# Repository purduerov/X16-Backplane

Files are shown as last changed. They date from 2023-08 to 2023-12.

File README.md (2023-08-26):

# Readme for X16-Backplane
This board routes signals and power between all the boards

Whenever you make a new part, download the datasheet and save it here _**and**_ with the part in the parts library

Always pull other people's changes before beginning to work
`git pull`

Be sure to push your changes after  working on them. Run:
1. `git add .` to add any files in this directory or a subdirectory
or `git add -u` to add any modified files
2. (Optional) `git clean -nX` to see what ignored files can be removed
	`git clean -fX` removes ignored files (Eagle backups)
3. `git commit -m "helpful commit message"` with a description of the work that you did
4. `git push` to push your work to github

Other helpful commands
* `git status` says information about modified and staged files
* `git log` shows the recent commits of the repository
* `git log filename.extension` show the recent commits for just that file
* `git checkout first-couple-letter-of-commit-id` lets you go back to a previous version
* `git checkout master` brings you back to the latest commit
* `git tag` lists the tags
* `git tag -a orderX -m "the version of the board placed for the X'th order"` tag a specific commit
* `git push --tags` needed to push tags to remote
* `git show orderX` show the commit log for the given tag
* `git checkout orderX` go back and interact with the files at the tagged commit

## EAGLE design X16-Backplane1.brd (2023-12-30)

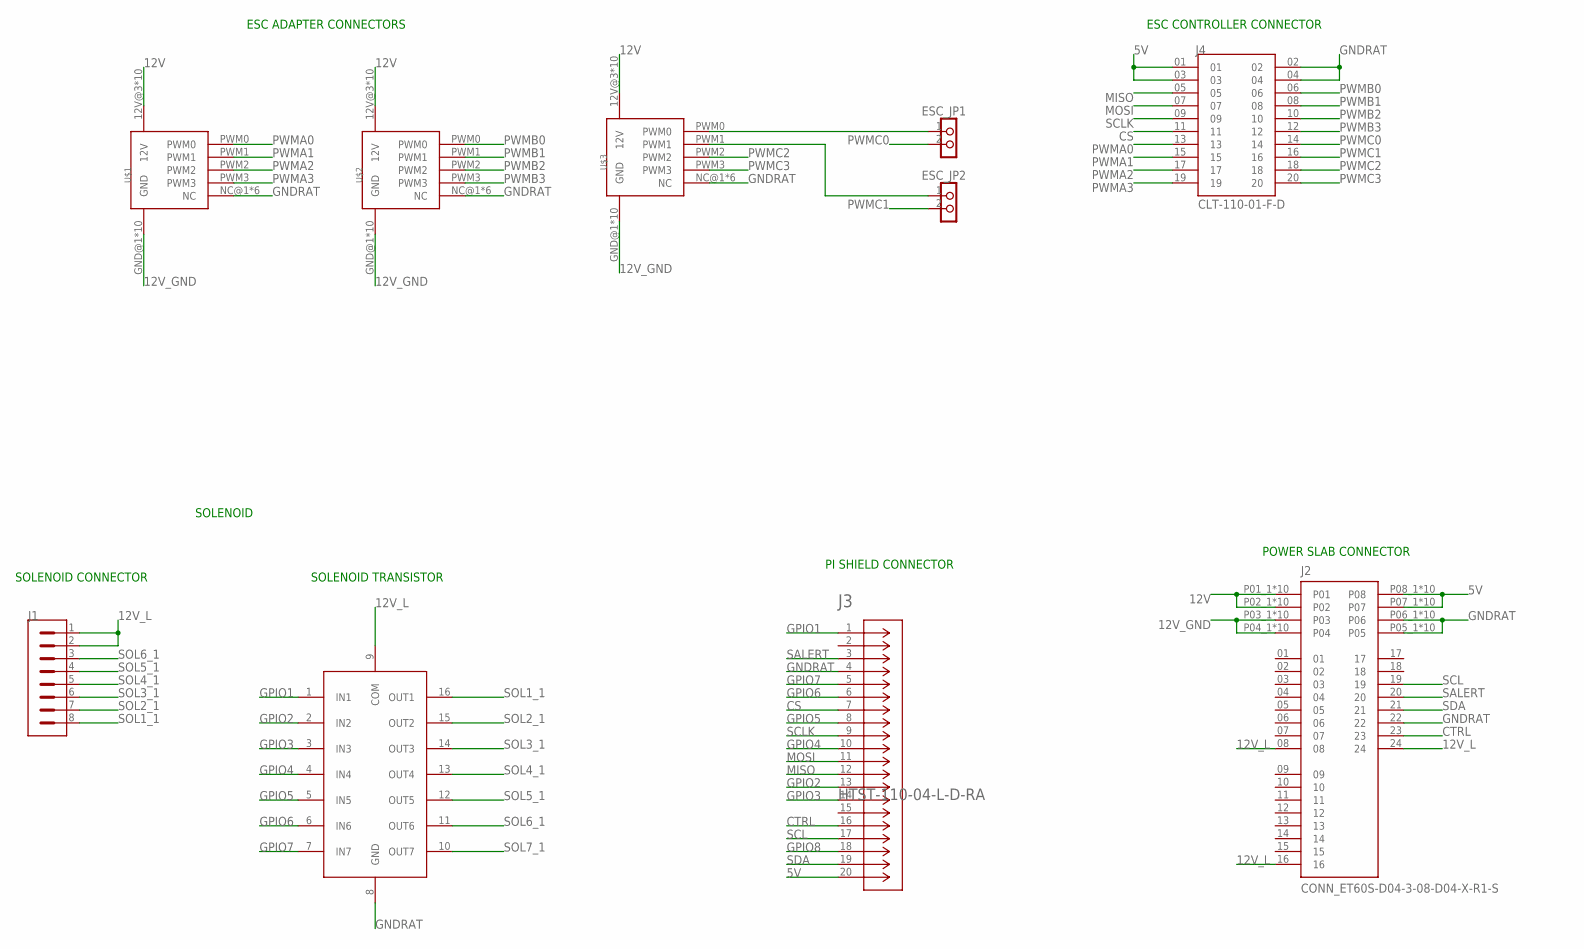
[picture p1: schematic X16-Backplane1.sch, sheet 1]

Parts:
ESC_JP1, ESC_JP2: TEST_PIN-1X2; 1X02
J1: CONN_PXC-8-RA-1778683; PXC-8-RA-1778683
J2: CONN_ET60S-D04-3-08-D04-X-R1-S; SAMTEC_ET60S-D04-3-08-D04-X-R1-S
J3: HTST-110-04-L-D-RA; CONN_HTST-110-04/05-X-D-RA_SAI
J4: CLT-110-01-F-D; SAMTEC_CLT-110-01-F-D
U2: TRANS_ULN2003AD; 16-SOIC
U$1, U$2, U$3: CONN_BACKPLANE_ESC_ADAPTER_NEW; CONN_BACKPLANE_ESC_ADAPTER

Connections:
5V: J2.P07_1 (P07), J2.P07_2 (P07), J2.P07_3 (P07), J2.P07_4 (P07), J2.P07_5 (P07), J2.P07_6 (P07), J2.P07_7 (P07), J2.P07_8 (P07), J2.P07_9 (P07), J2.P07_10 (P07), J2.P08_1 (P08), J2.P08_2 (P08), J2.P08_3 (P08), J2.P08_4 (P08), J2.P08_5 (P08), J2.P08_6 (P08), J2.P08_7 (P08), J2.P08_8 (P08), J2.P08_9 (P08), J2.P08_10 (P08), J3.20, J4.01, J4.03; also elsewhere on the board
12V: J2.P01_1 (P01), J2.P01_2 (P01), J2.P01_3 (P01), J2.P01_4 (P01), J2.P01_5 (P01), J2.P01_6 (P01), J2.P01_7 (P01), J2.P01_8 (P01), J2.P01_9 (P01), J2.P01_10 (P01), J2.P02_1 (P02), J2.P02_2 (P02), J2.P02_3 (P02), J2.P02_4 (P02), J2.P02_5 (P02), J2.P02_6 (P02), J2.P02_7 (P02), J2.P02_8 (P02), J2.P02_9 (P02), J2.P02_10 (P02), U$1.12V@3 (12V), U$1.12V@4 (12V), U$1.12V@5 (12V), U$1.12V@6 (12V), U$1.12V@7 (12V), U$1.12V@8 (12V), U$1.12V@9 (12V), U$1.12V@10 (12V), U$1.12V@11 (12V), U$1.12V@12 (12V), U$2.12V@3 (12V), U$2.12V@4 (12V), U$2.12V@5 (12V), U$2.12V@6 (12V), U$2.12V@7 (12V), U$2.12V@8 (12V), U$2.12V@9 (12V), U$2.12V@10 (12V), U$2.12V@11 (12V), U$2.12V@12 (12V), U$3.12V@3 (12V), U$3.12V@4 (12V), U$3.12V@5 (12V), U$3.12V@6 (12V), U$3.12V@7 (12V), U$3.12V@8 (12V), U$3.12V@9 (12V), U$3.12V@10 (12V), U$3.12V@11 (12V), U$3.12V@12 (12V); also elsewhere on the board
12V_GND: J2.P03_1 (P03), J2.P03_2 (P03), J2.P03_3 (P03), J2.P03_4 (P03), J2.P03_5 (P03), J2.P03_6 (P03), J2.P03_7 (P03), J2.P03_8 (P03), J2.P03_9 (P03), J2.P03_10 (P03), J2.P04_1 (P04), J2.P04_2 (P04), J2.P04_3 (P04), J2.P04_4 (P04), J2.P04_5 (P04), J2.P04_6 (P04), J2.P04_7 (P04), J2.P04_8 (P04), J2.P04_9 (P04), J2.P04_10 (P04), U$1.GND@1 (GND), U$1.GND@2 (GND), U$1.GND@3 (GND), U$1.GND@4 (GND), U$1.GND@5 (GND), U$1.GND@6 (GND), U$1.GND@7 (GND), U$1.GND@8 (GND), U$1.GND@9 (GND), U$1.GND@10 (GND), U$2.GND@1 (GND), U$2.GND@2 (GND), U$2.GND@3 (GND), U$2.GND@4 (GND), U$2.GND@5 (GND), U$2.GND@6 (GND), U$2.GND@7 (GND), U$2.GND@8 (GND), U$2.GND@9 (GND), U$2.GND@10 (GND), U$3.GND@1 (GND), U$3.GND@2 (GND), U$3.GND@3 (GND), U$3.GND@4 (GND), U$3.GND@5 (GND), U$3.GND@6 (GND), U$3.GND@7 (GND), U$3.GND@8 (GND), U$3.GND@9 (GND), U$3.GND@10 (GND); also elsewhere on the board
12V_L: J1.1, J1.2, J2.08, J2.16, J2.24, U2.9 (COM)
CS: J3.7, J4.11; also elsewhere on the board
CTRL: J2.23, J3.16
GNDRAT: J2.22, J2.P05_1 (P05), J2.P05_2 (P05), J2.P05_3 (P05), J2.P05_4 (P05), J2.P05_5 (P05), J2.P05_6 (P05), J2.P05_7 (P05), J2.P05_8 (P05), J2.P05_9 (P05), J2.P05_10 (P05), J2.P06_1 (P06), J2.P06_2 (P06), J2.P06_3 (P06), J2.P06_4 (P06), J2.P06_5 (P06), J2.P06_6 (P06), J2.P06_7 (P06), J2.P06_8 (P06), J2.P06_9 (P06), J2.P06_10 (P06), J3.4, J4.02, J4.04, U2.8 (GND), U$1.NC@1 (NC), U$1.NC@2 (NC), U$1.NC@3 (NC), U$1.NC@4 (NC), U$1.NC@5 (NC), U$1.NC@6 (NC), U$2.NC@1 (NC), U$2.NC@2 (NC), U$2.NC@3 (NC), U$2.NC@4 (NC), U$2.NC@5 (NC), U$2.NC@6 (NC), U$3.NC@1 (NC), U$3.NC@2 (NC), U$3.NC@3 (NC), U$3.NC@4 (NC), U$3.NC@5 (NC), U$3.NC@6 (NC); also elsewhere on the board
GPIO1: J3.1, U2.1 (IN1)
GPIO2: J3.13, U2.2 (IN2)
GPIO3: J3.14, U2.3 (IN3)
GPIO4: J3.10, U2.4 (IN4)
GPIO5: J3.8, U2.5 (IN5)
GPIO6: J3.6, U2.6 (IN6)
GPIO7: J3.5, U2.7 (IN7)
GPIO8: J3.18
MISO: J3.12, J4.05; also elsewhere on the board
MOSI: J3.11, J4.07; also elsewhere on the board
unnamed: ESC_JP1.1, U$3.PWM0
unnamed: ESC_JP2.1, U$3.PWM1
PWMA0: J4.13, U$1.PWM0
PWMA1: J4.15, U$1.PWM1
PWMA2: J4.17, U$1.PWM2
PWMA3: J4.19, U$1.PWM3
PWMB0: J4.06, U$2.PWM0
PWMB1: J4.08, U$2.PWM1
PWMB2: J4.10, U$2.PWM2
PWMB3: J4.12, U$2.PWM3
PWMC0: ESC_JP1.2, J4.14; also elsewhere on the board
PWMC1: ESC_JP2.2, J4.16; also elsewhere on the board
PWMC2: J4.18, U$3.PWM2
PWMC3: J4.20, U$3.PWM3
SALERT: J2.20, J3.3
SCL: J2.19, J3.17
SCLK: J3.9, J4.09; also elsewhere on the board
SDA: J2.21, J3.19
SOL1_1: J1.8, U2.16 (OUT1)
SOL2_1: J1.7, U2.15 (OUT2)
SOL3_1: J1.6, U2.14 (OUT3)
SOL4_1: J1.5, U2.13 (OUT4)
SOL5_1: J1.4, U2.12 (OUT5)
SOL6_1: J1.3, U2.11 (OUT6)
SOL7_1: U2.10 (OUT7)

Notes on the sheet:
ESC ADAPTER CONNECTORS
SOLENOID
POWER SLAB CONNECTOR
SOLENOID TRANSISTOR
SOLENOID CONNECTOR
ESC CONTROLLER CONNECTOR
PI SHIELD CONNECTOR

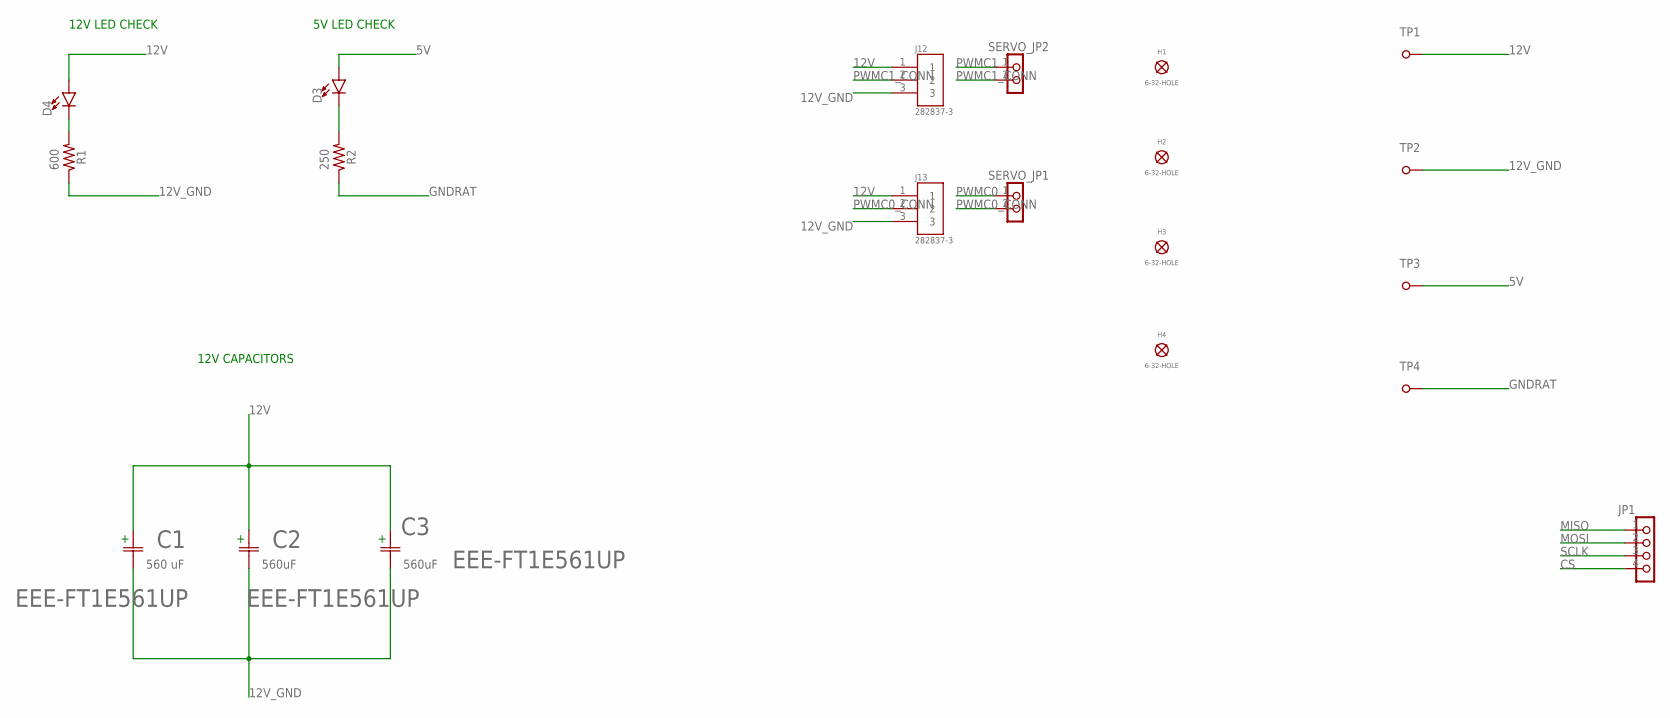
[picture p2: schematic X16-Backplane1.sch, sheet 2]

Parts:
C1, C2, C3: EEE-FT1E561UP; CAP_FT_F_PAN
D3, D4: LEDCHIPLED_0805; CHIPLED_0805
H1, H2, H3, H4: 6-32-HOLE
J12, J13: 282837-3; TE_282837-3
JP1: TEST_PIN-1X4; 1X04
R1, R2: 0603
SERVO_JP1, SERVO_JP2: TEST_PIN-1X2; 1X02
TP1, TP2, TP3, TP4: TESTPOINT_5.04MM

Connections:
5V: D3.A, TP3.TP; also elsewhere on the board
12V: C1.1, C2.1, C3.1, D4.A, J12.1, J13.1, TP1.TP; also elsewhere on the board
12V_GND: C1.2, C2.2, C3.2, J12.3, J13.3, R1.1, TP2.TP; also elsewhere on the board
CS: JP1.4; also elsewhere on the board
GNDRAT: R2.1, TP4.TP; also elsewhere on the board
MISO: JP1.1; also elsewhere on the board
MOSI: JP1.2; also elsewhere on the board
unnamed: D4.C, R1.2
unnamed: D3.C, R2.2
PWMC0: SERVO_JP1.1; also elsewhere on the board
PWMC0_CONN: J13.2, SERVO_JP1.2
PWMC1: SERVO_JP2.1; also elsewhere on the board
PWMC1_CONN: J12.2, SERVO_JP2.2
SCLK: JP1.3; also elsewhere on the board

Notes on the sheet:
12V LED CHECK
5V LED CHECK
12V CAPACITORS

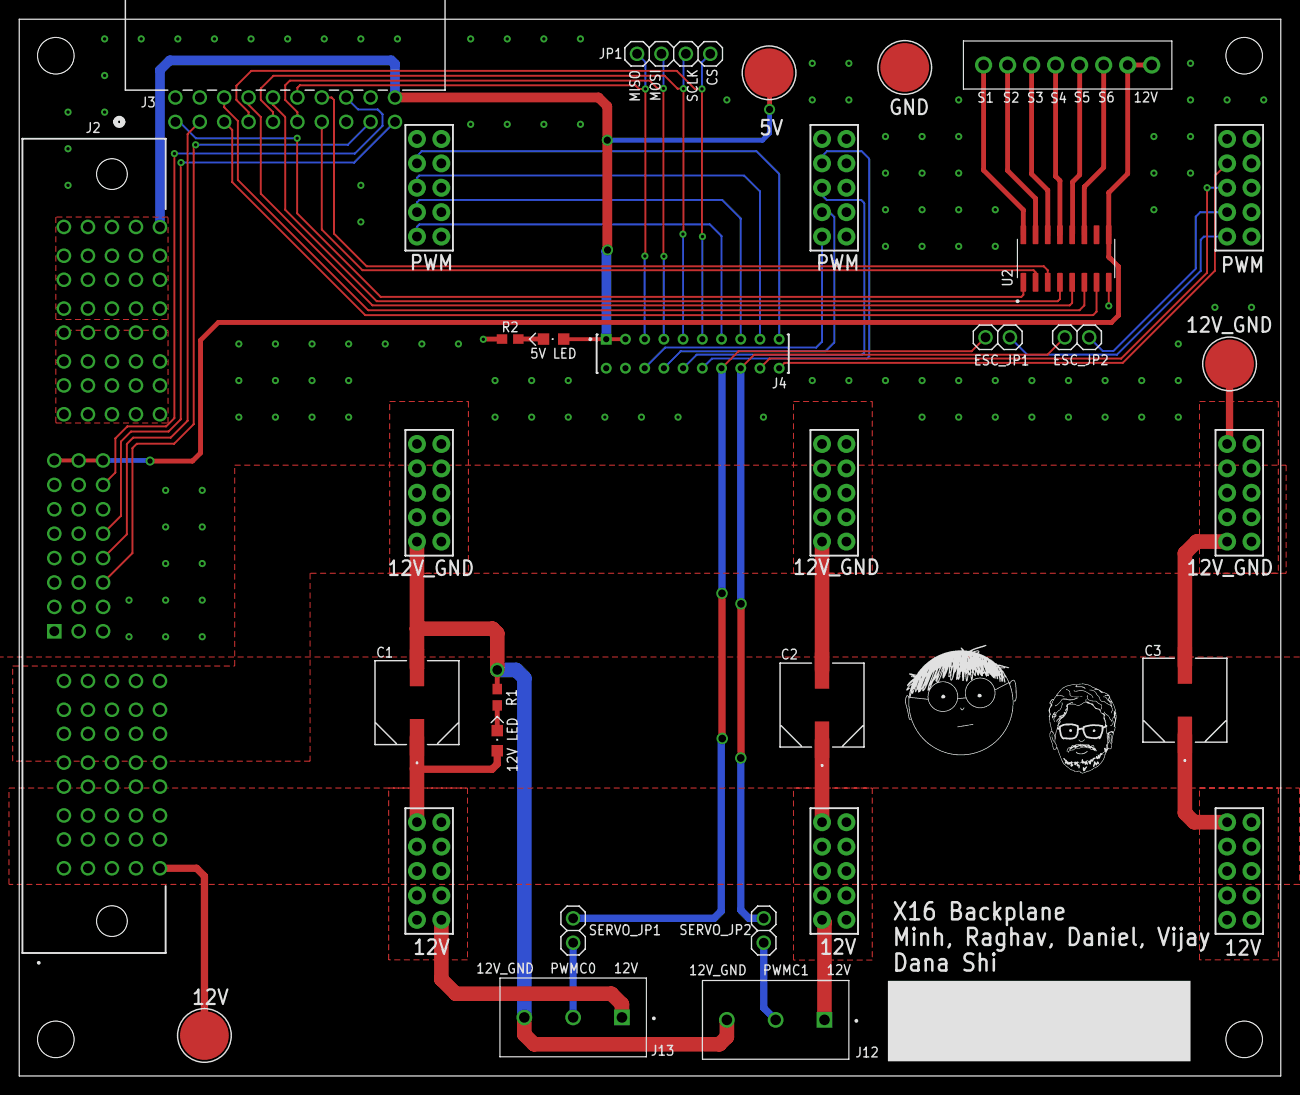
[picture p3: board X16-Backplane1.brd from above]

Board: 2 copper layers, 131.3 x 110.0 mm, 30 parts (0 on the bottom side), 44 nets.

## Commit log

2023-08-30 added tentative dimensions
    [X16-Backplane.brd, X16-Backplane.sch]
2023-10-11 Added board dimensions and removed unneeded files
    [X16-Backplane.brd]
2023-10-14 10/14 sch issues fixed
    [X16-Backplane.sch]
2023-11-04 Added new backplane to pi connector to use that has enough pins in footprint
2023-12-20 Minh Update 1
    [X16-Backplane1.brd, X16-Backplane1.sch]
2023-12-21 Minh Update 3
    [X16-Backplane1.brd, X16-Backplane1.sch]
2023-12-21 few extra labels and got rid of wire stubs from drc
    [X16-Backplane1.brd]
2023-12-23 Minh Update 4
    [X16-Backplane1.brd]
2023-12-23 Revert "Minh Update 4"
    This reverts commit 6540dcb78246fca95661c726553611ac5071b16d.
    [X16-Backplane1.brd]
2023-12-23 Minh Update 5
    [X16-Backplane1.brd, X16-Backplane1.sch]
2023-12-29 Minh Update 6
    [X16-Backplane1.brd, X16-Backplane1.sch]
2023-12-29 Minh Update 7
    [X16-Backplane1.brd]
2023-12-30 GERBER file created
    [X16-Backplane1.brd, X16-Backplane1.sch]

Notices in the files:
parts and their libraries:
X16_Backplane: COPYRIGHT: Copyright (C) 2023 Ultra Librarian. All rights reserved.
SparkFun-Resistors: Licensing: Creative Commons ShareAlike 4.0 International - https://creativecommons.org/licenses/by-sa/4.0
